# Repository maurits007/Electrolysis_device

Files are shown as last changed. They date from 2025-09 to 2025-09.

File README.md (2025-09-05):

# Electrolysis Device Controller – Arduino R4 Wifi

## Version
**v1.0** – Last updated: 2025-09-05  

---

## Table of Contents
1. [Overview](#overview)  
2. [Startup](#startup)  
3. [Normal Usage](#normal-usage)  
4. [Buttons](#buttons)  
5. [Main menu](#main-menu)  
6. [Advanced Settings / Calibration](#advanced-settings--calibration)  
7. [LED Indicators](#led-indicators)  
8. [Bugs / Troubleshooting](#bugs--troubleshooting) 
9. [Values achieved](#values-achieved) 

---

## Overview
This Arduino project allows you to control an electrolysis device via a physical interface (buttons and OLED) or a web interface through WiFi.  
You can set the desired current, the operating time, and monitor voltage, current, and resistance in real-time.

---

## Startup
1. The Arduino will create a WiFi hotspot:  
   - **SSID:** `ArduinoAP`  
   - **Password:** `12345678`  
2. Connect to the WiFi (if wanted) and access the web server using a browser:  
   - Type the IP address shown on the bottom of the OLED screen (usually `192.168.4.1`).  
3. Connect the electrolysis device to the PCB:  
   - **Red wire:** `Ld +`  
   - **Black wire:** `Ld -`  
   - If connected correctly, the LED should light **yellow/green** (not red).  

---

## Normal Usage
1. Start the device and optionally connect via WiFi.  
2. Connect the electrolysis device as described above.  
3. Select the desired current (`I want`) and time (`Time`).  
4. Press the **small button** to start:  
   - The LED turns **green** if running.  
   - The OLED shows `I real` (actual current) and elapsed time.  
5. When the reaction is complete:  
   - LED turns **blue**.  
   - The ending screen is displayed.  
   - Press the small button or use the web interface to restart.  

---

## Buttons

| Button | Function |
|---|---|
| **Encoder (turnable)** | Select a menu line by turning. Press to start editing the value. Press again to stop editing. |
| **Small button** | Start/stop electrolysis. LED indicates the device state. |

---

## Main menu
The OLED screen has **8 lines**:

| Line | Description |
|---|---|
| Time | Time passed / total wanted time |
| I want | Desired current |
| I real | Actual current through the device |
| V load | Voltage across the device (mV) |
| R load | Device resistance (ohms) – inaccurate if device is off |
| Reset time | Reset the timer to restart the electrolysis reaction |
| Advanced Settings | Access [calibration options](#advanced-settings--calibration ) and PCB selection |
| IP | IP address to access the web interface |

> Bottom-right corner: ❚❚ (paused) or ▶ (running)

---

## Advanced Settings / Calibration
The advanced menu has **5 lines**:

Here the PCB can be calibrated.

| Line | Description |
|---|---|
| PCB number | Select which PCB configuration to use (2 saved configurations supported) |
| Cur. res. | Current sense resistor value for calibration |
| A0 | Multiplier for output voltage calibration (`I load`) |
| A1 | Multiplier for measured current calibration (`I meas`) |
| Load | Multiplier for measured voltage over the load |

---

## LED Indicators

| Color | Meaning |
|---|---|
| Red | Device not connected correctly |
| Yellow | Electrolysis off |
| Green | Electrolysis running |
| Blue | Electrolysis finished |

---

## Bugs / Troubleshooting
- **OLED screen freezes:** Unplug and plug the Arduino back in.  
- **Red LED stays on:** Check that `Ld +` and `Ld -` are connected correctly.  
- **Keeps pausing:** There is a safety measure if there is too much power over the MOSFET. Increasing or decreasing the current both help decreasing the power and the device will be able to start again.

## Values achieved
- **No external voltage:** 210 mA
- **6V ext:** 350mA

---
-------
## Future extensions
- **Using external voltage:** First voltage dividers and zener diodes have to be added to the pins reading the voltage over the load to protect it against overvoltage.
- **using 3V3 as ADC reference:** Currently no significant improvements were found using it.

- **Improvements PCB:**
   1. Make holes LCD screen bigger.
   2. Correct orientation MOSFET or replace by through-hole MOSFET
   3. To use pin A4, A5 the screen has to be connected to QWIIC.

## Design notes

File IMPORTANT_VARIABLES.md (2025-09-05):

## deviceStats[7]
|Index | |
|-|-|
|0 |Last reset time|
|1 |Total wanted time (s)|
|2 |Desired current (mA)|
|3 |Actual current (mA)|
|4 |Load voltage (mV)|
|5 |Output enabled flag|
|6 |Resistance of the load (ohm)|

## correctionVariables[4][2]:
Here the calibration variables are saved.

||**Device 1** / **Device 2** | 
|----|---|
|1| A0 correction| 
|2| A1 correction|
|3| current_sense_resistor|
|4| load voltage correction|

## PIN Definition
| **Pin Nr.** | Meaning|
|---|-|
|A0 | Output Voltage (DAC)|
|A1 | Current Sense Resistor (ADC)|
|A2 | Load Voltage Negative (ADC)|
|A3 | Load Voltage Positive (ADC)|
|A4 | SDA (I2C)|
|A5 | SCL (I2C)|
|2  | Encoder A|
|3  | Encoder B|
|6  | Encoder Button|
|8  | Small Button|

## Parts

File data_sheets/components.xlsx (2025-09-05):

Reference | Qty | Value | RS-link | Found | Footprint | Datasheet
A1 | 1 | Arduino_Uno_R4_WiFi_Shield | //// | TRUE | PCM_arduino-library:Arduino_Uno_R4_WiFi_Shield | https://docs.arduino.cc/hardware/uno-r4-wifi
C1 | 1 | 100n | 199-2385 | TRUE | Capacitor_SMD:C_1210_3225Metric_Pad1.33x2.70mm_HandSolder | ~
D1 | 1 | LED_GBAR | already have them | TRUE | LED_THT:LED_D5.0mm-4_RGB | ~
D2,D3 | 2 | D_Zener | 738-5046 | TRUE | Diode_SMD:D_SOD-123 | ~
IC1 | 1 | AD8531ARZ-REEL | already have them | TRUE | Package_SO:SOIC-8_3.9x4.9mm_P1.27mm | https://www.analog.com/AD8531/datasheet
J2 | 1 | Conn_01x04_Socket | 3287528 (Farnell) | FALSE | Connector:NS-Tech_Grove_1x04_P2mm_Vertical | kicad-embed://Connector_i2c.pdf
J3 | 1 | Conn_01x04_Socket | magazijn | TRUE | Connector_Phoenix_MSTB:PhoenixContact_MSTBVA_2,5_4-G-5,08_1x04_P5.08mm_Vertical | ~
J4 | 1 | Conn_01x03_Pin | 702-0105, 233-9724 | TRUE | Connector_PinHeader_1.27mm:PinHeader_1x03_P1.27mm_Vertical | ~
Q1 | 1 | BS170 | 708-2393 | TRUE | Package_TO_SOT_SMD:SOT-23_Handsoldering | https://www.onsemi.com/pub/Collateral/BS170-D.PDF
R1 | 1 | 150 | 198-8555 | TRUE | Resistor_SMD:R_2512_6332Metric_Pad1.40x3.35mm_HandSolder | ~
R2,R3 | 2 | 90 | will use 100 | TRUE | Resistor_SMD:R_2512_6332Metric_Pad1.40x3.35mm_HandSolder | ~
R4 | 1 | 1k | 198-8564 | TRUE | Resistor_SMD:R_2512_6332Metric_Pad1.40x3.35mm_HandSolder | ~
R5 | 1 | 100 | 198-8549 | TRUE | Resistor_SMD:R_2512_6332Metric_Pad1.40x3.35mm_HandSolder | ~
R6 | 1 | 1R1 | 198-8566 | TRUE | Resistor_SMD:R_2512_6332Metric_Pad1.40x3.35mm_HandSolder | ~
R7 | 1 | 43k |  | TRUE | Resistor_SMD:R_2512_6332Metric_Pad1.40x3.35mm_HandSolder | ~
R9,R10 | 2 | 0 | 198-8545 | TRUE | Resistor_SMD:R_2512_6332Metric_Pad1.40x3.35mm_HandSolder | ~
R11,R12,R13,R14 | 4 | ~ |  | FALSE | Resistor_SMD:R_2512_6332Metric_Pad1.40x3.35mm_HandSolder | ~
U2 | 1 | MDOB | already have them | TRUE | Custom_footprints:MDOB128064V2V-WI | kicad-embed://display_oled.pdf
U3 | 1 | ~ | already have them | TRUE | Custom_footprints:MC32831
U4 | 1 | ~ | already have them | TRUE | Custom_footprints:PEC11R-4215K-S0012
R8 |  | 12k | 755-1344P | TRUE
 |  |  |  | FALSE
 |  |  |  | FALSE

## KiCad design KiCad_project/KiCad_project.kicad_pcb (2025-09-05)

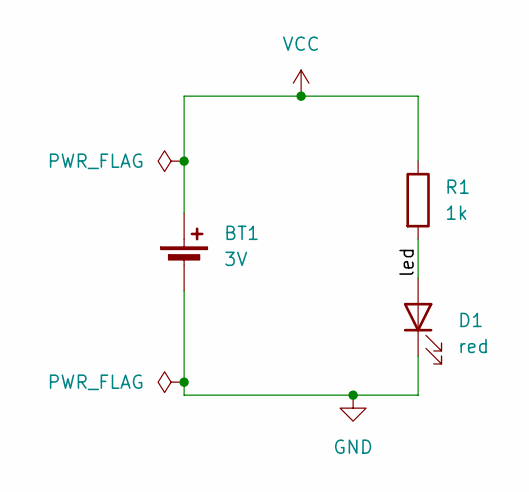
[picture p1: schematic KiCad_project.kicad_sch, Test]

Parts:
BT1: 3V; BatteryHolder_Keystone_1058_1x2032
D1: red; LED_D5.0mm
R1: 1k; R_Axial_DIN0309_L9.0mm_D3.2mm_P12.70mm_Horizontal

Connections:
/led: D1.2 (A), R1.2
GND: BT1.2 (-), D1.1 (K)
VCC: BT1.1 (+), R1.1

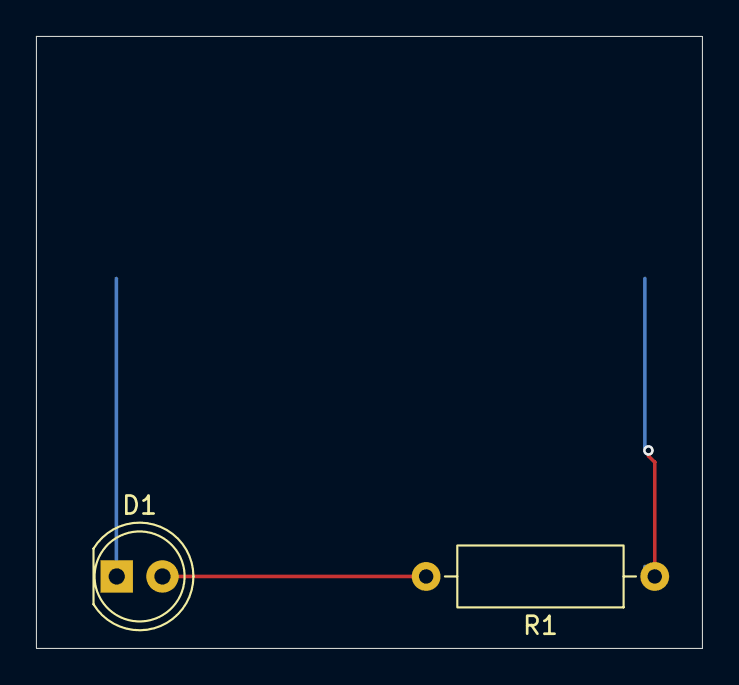
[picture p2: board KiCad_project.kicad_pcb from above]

Board: 2 copper layers, 37.0 x 34.0 mm, 3 parts (1 on the bottom side), 3 nets.

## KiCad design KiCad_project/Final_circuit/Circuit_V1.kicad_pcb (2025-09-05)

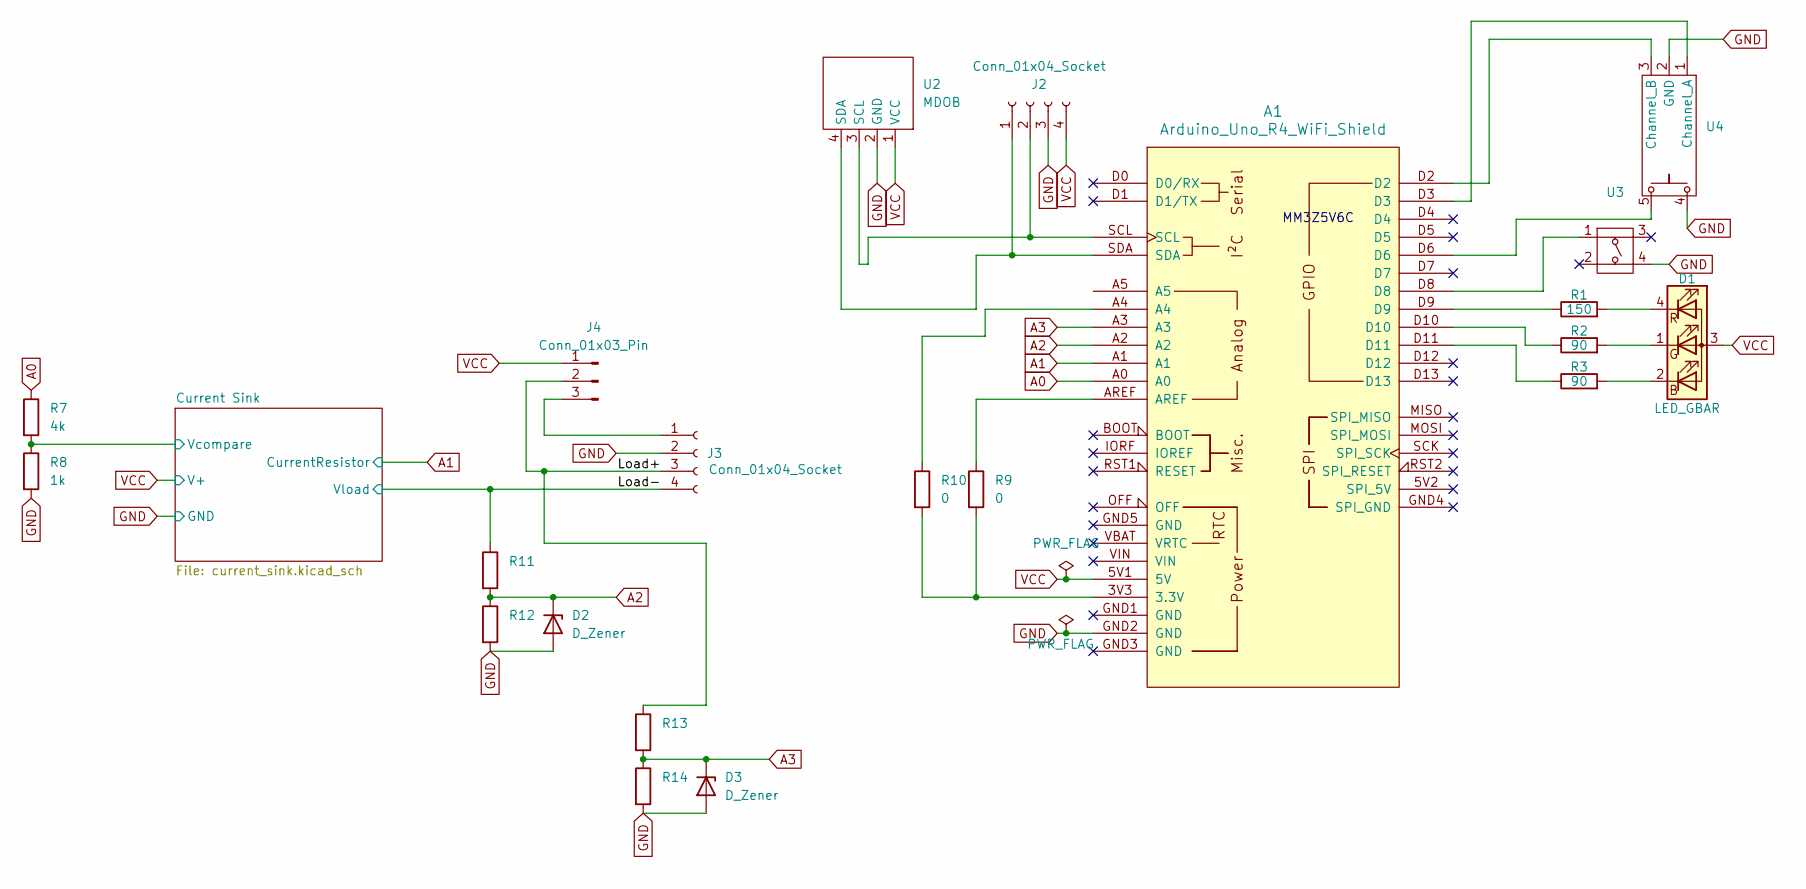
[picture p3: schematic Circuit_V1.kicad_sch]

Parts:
A1: Arduino_Uno_R4_WiFi_Shield
D1: LED_GBAR; LED_D5.0mm-4_RGB
D2, D3: D_Zener; D_SOD-123
J2: Conn_01x04_Socket; NS-Tech_Grove_1x04_P2mm_Vertical
J3: Conn_01x04_Socket; PhoenixContact_MSTBVA_2,5_4-G-5,08_1x04_P5.08mm_Vertical
J4: Conn_01x03_Pin; PinHeader_1x03_P1.27mm_Vertical
R1: 150; R_2512_6332Metric_Pad1.40x3.35mm_HandSolder
R2, R3: 90; R_2512_6332Metric_Pad1.40x3.35mm_HandSolder
R7: 4k; R_2512_6332Metric_Pad1.40x3.35mm_HandSolder
R8: 1k; R_2512_6332Metric_Pad1.40x3.35mm_HandSolder
R9, R10: 0; R_2512_6332Metric_Pad1.40x3.35mm_HandSolder
R11, R12, R13, R14: R_2512_6332Metric_Pad1.40x3.35mm_HandSolder
U2: MDOB; MDOB128064V2V-WI
U3: MC32831
U4: PEC11R-4215K-S0012

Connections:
/Current Sink/Vcompare: R7.2, R8.1; also elsewhere on the board
/Load+: J3.3, J4.2, R13.1
/Load-: J3.4, R11.1; also elsewhere on the board
A0: A1.A0, R7.1
A1: A1.A1; also elsewhere on the board
A2: A1.A2, D2.1 (K), R11.2, R12.1
A3: A1.A3, D3.1 (K), R13.2, R14.1
GND: A1.GND2 (GND), D2.2 (A), D3.2 (A), J2.3, J3.2, R8.2, R12.2, R14.2, U2.2 (GND), U3.4, U4.2 (GND), U4.4; also elsewhere on the board
unnamed: A1.3V3 (3.3V), R9.2, R10.2
unnamed: A1.A4, R10.1
unnamed: A1.AREF, R9.1
unnamed: A1.D6, U4.5
unnamed: A1.D8, U3.1
unnamed: A1.D9, R1.1
unnamed: A1.D10, R2.1
unnamed: A1.D11, R3.1
unnamed: D1.2 (BK), R3.2
unnamed: D1.1 (GK), R2.2
unnamed: D1.4 (RK), R1.2
unnamed: A1.SDA, J2.1, U2.4 (SDA)
unnamed: A1.SCL, J2.2, U2.3 (SCL)
unnamed: J3.1, J4.3
unnamed: A1.D3, U4.1 (Channel_A)
unnamed: A1.D2, U4.3 (Channel_B)
VCC: A1.5V1 (5V), D1.3 (A), J2.4, J4.1, U2.1 (VCC); also elsewhere on the board

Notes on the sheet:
MM3Z5V6C

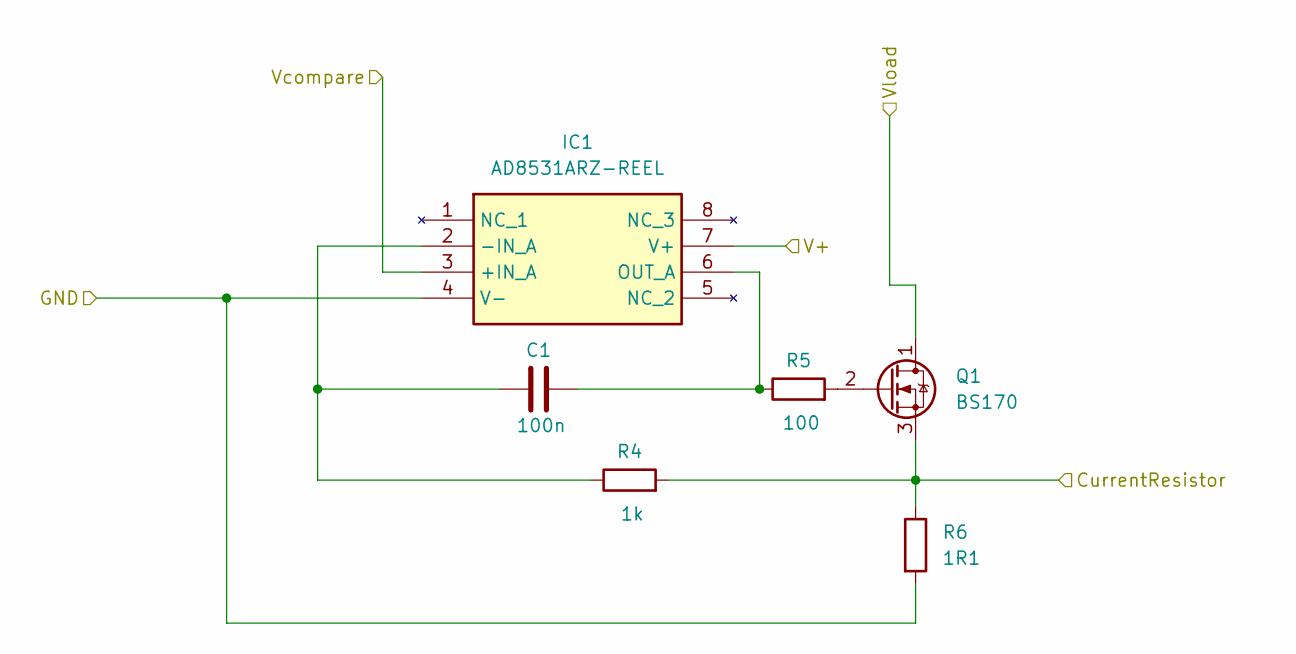
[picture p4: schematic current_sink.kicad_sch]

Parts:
C1: 100n; C_1210_3225Metric_Pad1.33x2.70mm_HandSolder
IC1: AD8531ARZ-REEL; SOIC-8_3.9x4.9mm_P1.27mm; Mouser Part Number 584-AD8531ARZ-R
Q1: BS170; SOT-23_Handsoldering
R4: 1k; R_2512_6332Metric_Pad1.40x3.35mm_HandSolder
R5: 100; R_2512_6332Metric_Pad1.40x3.35mm_HandSolder
R6: 1R1; R_2512_6332Metric_Pad1.40x3.35mm_HandSolder

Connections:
/Current Sink/Vcompare: IC1.3 (+IN_A); also elsewhere on the board
/Load-: Q1.1 (D); also elsewhere on the board
A1: Q1.3 (S), R4.2, R6.1; also elsewhere on the board
GND: IC1.4 (V-), R6.2; also elsewhere on the board
unnamed: C1.1, IC1.2 (-IN_A), R4.1
unnamed: C1.2, IC1.6 (OUT_A), R5.1
unnamed: Q1.2 (G), R5.2
VCC: IC1.7 (V+); also elsewhere on the board

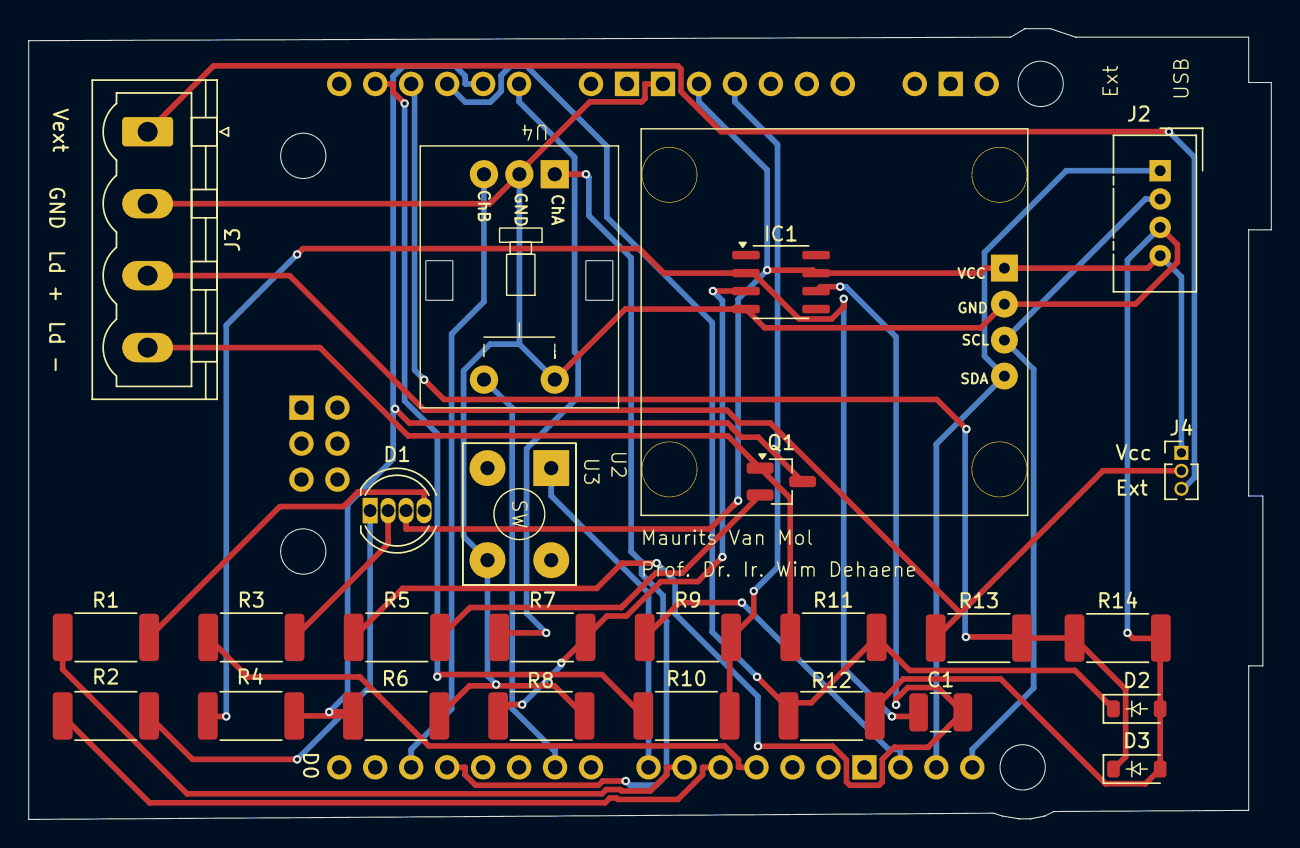
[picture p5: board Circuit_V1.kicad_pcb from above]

Board: 2 copper layers, 87.8 x 55.8 mm, 27 parts (0 on the bottom side), 28 nets.

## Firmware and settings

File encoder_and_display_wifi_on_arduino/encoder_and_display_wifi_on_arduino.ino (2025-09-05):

//===================== CALIBRATION =======================
#define CURRENT_SENSE_RESISTOR_1 0.56
#define CURRENT_SENSE_RESISTOR_2 1
float current_sense_resistor[2] =  {CURRENT_SENSE_RESISTOR_1, CURRENT_SENSE_RESISTOR_2};
float A0Correction[2] = {1.02, 1.07};
float A1Correction[2] = {1, 0.91};
float loadVoltageCorrection[2] = {1, 1};
float correctionVariables[4][2] = {
  { A0Correction[0], A0Correction[1] },        // A0
  { A1Correction[0], A1Correction[1] },        // A1
  { current_sense_resistor[0], current_sense_resistor[1] }, // current sense
  { loadVoltageCorrection[0], loadVoltageCorrection[1] }    // load voltage
};
float oldCorrectionVariables[4][2];
int numbPCB = 0;
#define Vdd 4.56
#define Vext 4.56


//====================== WIFI SETTINGS =======================
#include <WiFiS3.h>
#include "webpage.h"
    
WiFiServer server(80);  // Create a WebServer object on port 80
char ssid[] = "ArduinoAP";       // Network SSID
char pass[] = "12345678";        // Password (at least 8 chars)


//====================== LIBRARIES =======================

#include <EEPROM.h>
#include <Wire.h>
#include <Adafruit_GFX.h>
#include <Adafruit_SSD1306.h>
#include "utils.h"

//=============Function prototypes===================
void redOn();
void greenOn();
void yellowOn();
void blueOn();
void pinkOn();
void readEncoder();
void onEncoderButtonPress();
void onSmallButtonPress();


//======================Global Variables======================
int timeFinished = 0; //Time when it finished, to display in ending screen
bool overVoltage = false; //if goes high, it shows overvoltage warning in stats screen

//====================== PIN DEFINITIONS =======================
#define SDA_PIN A4   // adjust if not on Arduino Uno/Nano
#define SCL_PIN A5
#define ENCODER_PIN_A       3
#define ENCODER_PIN_B       2
#define ENCODER_BUTTON_PIN  6
#define SMALL_BUTTON_PIN    8
#define OLED_RESET         4
#define ledR 9
#define ledB 11
#define ledG 10
/*****************
 Pin Connections:
   A0 -> Output Voltage
   A1 -> Current Sense Resistor
   A2 -> Load Voltage Negative
   A3 -> Load Voltage Positive
   A4 -> SDA (I2C)
   A5 -> SCL (I2C)
   2  -> Encoder A
   3  -> Encoder B
   6  -> Encoder Button
   8  -> Small Button
******************/


//====================== OLED Display =======================
#define SCREEN_WIDTH  128
#define SCREEN_HEIGHT 64
Adafruit_SSD1306 display(SCREEN_WIDTH, SCREEN_HEIGHT, &Wire, OLED_RESET);



/******************** Encoder Variables *******************/
volatile int encoderCount = 0; 
volatile bool encoderButtonPressedFlag = false;
volatile bool smallButtonPressedFlag = false;

volatile unsigned long lastEncoderButtonInterrupt = 0; 
volatile unsigned long lastSmallButtonInterrupt = 0;

unsigned long lastIncrementTime = micros();
unsigned long lastDecrementTime = micros();

const int encoderFastStep = 3; //if quickly turning, it will change by this value
const int encoderDebounceMicros = 25000; //reduce against bouncing


/******************** Menu System *************************/
bool isEditing = false;
int menuCursor = 0;
bool showStatsScreen = 1;
bool showAdvancedMenu = 0;
bool reset = 1; //reset the values of stats screen
bool reset_ending = 0; //lets the ending screen know it should reset
bool toggleStartWifi = 0; //if start is pressed by web server
int elapsedTime = 0;
int timePassed = 0;



/******************** Measurements ************************/
int deviceStats[7] = {0, 60, 3, 44, 0, false, 0}; 
// [0] Last reset time
// [1] Total wanted time (s)
// [2] Desired current (mA)
// [3] Actual current (mA)
// [4] Load voltage (mV)
// [5] Output enabled flag
// [6] Resistance of the load (ohm)

int oldWantedTime = deviceStats[1]; //to check if it changed to updated EEPROM
int oldDesiredCurrent = deviceStats[2]; //idem
int oldnumbPCB = numbPCB; //idem
int voltageSenseRaw = 0; //raw value from ADC over current sense resistor
float voltageSense = 0.0;  //voltage over current sense resistor
int outputVoltageCommand = 0; //digital value to set output voltage over DAC


/******************** Setup *******************************/
void setup() {
  // ====== Serial Setup ======
  Serial.begin(500000);
  pinMode(ledR, OUTPUT);
  pinMode(ledB, OUTPUT);
  pinMode(ledG, OUTPUT);
  blueOn();
  while(!Serial);  // wait for Serial

  // ====== Encoder Setup ======
  // analogReference(AR_EXTERNAL);
  pinMode(ENCODER_PIN_A, INPUT_PULLUP);
  pinMode(ENCODER_PIN_B, INPUT_PULLUP);
  pinMode(ENCODER_BUTTON_PIN, INPUT_PULLUP);
  pinMode(SMALL_BUTTON_PIN, INPUT_PULLUP);
  attachInterrupt(digitalPinToInterrupt(ENCODER_PIN_A), readEncoder, CHANGE);
  attachInterrupt(digitalPinToInterrupt(ENCODER_PIN_B), readEncoder, CHANGE);
  attachInterrupt(digitalPinToInterrupt(ENCODER_BUTTON_PIN), onEncoderButtonPress, FALLING);
  attachInterrupt(digitalPinToInterrupt(SMALL_BUTTON_PIN), onSmallButtonPress, FALLING);

  // ====== Analog Setup ======
  analogReadResolution(12);
  analogWriteResolution(12);

  // ====== EEPROM Setup ======
  EEPROM.get(0, deviceStats[1]);
  EEPROM.get(4, deviceStats[2]);
  EEPROM.get(8, numbPCB);
  EEPROM.get(16, correctionVariables);


  oldDesiredCurrent = deviceStats[2]; //save values from EEPROM
  oldWantedTime = deviceStats[1];
  oldnumbPCB = numbPCB;
  for (int i=0; i<4; i++){
    for (int j=0; j<2; j++){
      oldCorrectionVariables[i][j] = correctionVariables[i][j];
    }
  }


  // ====== OLED Setup ======
  if (!display.begin(SSD1306_SWITCHCAPVCC, 0x3C)) {
    Serial.println(F("SSD1306 allocation failed"));
    while (true);
  }
  display.clearDisplay();
  display.fillScreen(SSD1306_BLACK);
  display.setTextColor(SSD1306_WHITE);
  display.setTextSize(2);
  display.setCursor(0, 0);
  display.println("Connecting");
  display.println("to the");
  display.println("wifi!");
  display.setTextSize(1);
  display.println("Small button -> no wifi");
  display.display();

  // ====== WiFi Setup ======
  Serial.println("Starting Access Point…");
  int status = WiFi.beginAP(ssid, pass);
  if (status != WL_AP_LISTENING) {
    Serial.println("Failed to start AP");
    while (true);
  }
  // Print the IP address of the AP (usually 192.168.4.1)
  Serial.print("AP started. IP address: ");
  Serial.println(WiFi.localIP());
  server.begin();

}


/******************** Main Loop ***************************/
void loop() {
  //===================== Read Sensors =======================
    int voltageLoadRawPos = analogRead(A3);//voltage over the load
    int voltageLoadRawNeg = analogRead(A2);
    int voltageLoadDiffRaw = voltageLoadRawPos - voltageLoadRawNeg;
    deviceStats[4] = correctionVariables[3][numbPCB]*Vext*1000.0 * voltageLoadDiffRaw / 4096;
    voltageSenseRaw = analogRead(A1); //current sense resistor
    voltageSense = correctionVariables[1][numbPCB]*Vext*1000.0 * voltageSenseRaw / (4096.0);
    deviceStats[3] = voltageSense / correctionVariables[2][numbPCB];
    // deviceStats[3] = voltageSense;
    deviceStats[6] = deviceStats[4]/deviceStats[3]; //resistance of the load
    int vdsRaw = voltageLoadRawNeg - voltageSenseRaw; //voltage over the mosfet
    float vds = correctionVariables[0][numbPCB]*Vext * vdsRaw / 4096.0;
    float powerDissipated = vds * deviceStats[3]; //in mW
    if(powerDissipated > 400){ //if too much power dissipated, turn off output
      overVoltage = true;
    }
    // Calculate output voltage command
    outputVoltageCommand = correctionVariables[0][numbPCB]*deviceStats[2] * correctionVariables[2][numbPCB] * 4096 / (Vdd*1000);
    // Write to output
    if (!deviceStats[5]) {
      analogWrite(A0, 0);
    } else {
      analogWrite(A0, outputVoltageCommand);
    }
    //===================== LIGHTS =======================

    if(!showStatsScreen){
      blueOn();
    }
    else if(deviceStats[5]){
        greenOn();
      }
    else if(voltageLoadDiffRaw > 4096*0.93){
      redOn();
    }
    else{
      yellowOn();
    }
  //===================== MENU =======================
  const char* (*menuFunctions[])(int*, bool*, bool*, int*, bool) = { //functions for each menu item
    timeMenuItem,
    desiredCurrentMenuItem,
    resetTimeMenuItem,
    advancedScreenItem,
    actualCurrentMenuItem,
    voltageMenuItem,
    resistanceMenuItem,
    ipMenuItem
  };  
  AdvancedItemFn menuFunctionsAdvanced[] = {
    PCB_numberMenuItem,
    currentResistorMenuItem,
    A0CorrectionMenuItem,
    A1CorrectionMenuItem,
    loadCorrectionMenuItem
    // add the others here
  };

  int menuOrder[] = {0, 1, 4, 5, 6, 2, 3, 7};
  int menuOrderAdvanced[] = {0, 1, 2, 3, 4};
  //check if time is finished
  if(((millis()-deviceStats[0])/1000 >= deviceStats[1]) && deviceStats[5]){
    showStatsScreen = 0;
    timeFinished = (millis() - deviceStats[0])/1000;
  }
  if(showAdvancedMenu){
    renderAdvancedMenu(
        menuFunctionsAdvanced,
        correctionVariables,
        sizeof(menuFunctionsAdvanced) / sizeof(menuFunctionsAdvanced[0]),
        (bool*)&encoderButtonPressedFlag,
        &menuCursor,
        &isEditing,
        (int*)&encoderCount,
        menuOrderAdvanced,
        (bool*)&smallButtonPressedFlag,
        &reset
      );
  }
  else if(showStatsScreen){
    showStatsScreen = renderStatsMenu(
        menuFunctions,
        deviceStats,
        sizeof(menuFunctions) / sizeof(menuFunctions[0]),
        (bool*)&encoderButtonPressedFlag,
        &menuCursor,
        &isEditing,
        (int*)&encoderCount,
        menuOrder,
        (bool*)&smallButtonPressedFlag, 
        &reset,
        &toggleStartWifi
      );
  }
  else{
    showStatsScreen = renderEnding(deviceStats, (bool*)&smallButtonPressedFlag, &reset_ending);
    deviceStats[5] = 0;
    reset = 1;
  }


  //===================== SAVE EEPROM =======================
  if(oldDesiredCurrent != deviceStats[2]){
    EEPROM.put(4, deviceStats[2]);
    oldDesiredCurrent = deviceStats[2];
  }
  if(oldWantedTime != deviceStats[1]){
    EEPROM.put(0, deviceStats[1]);
    oldDesiredCurrent = deviceStats[1];
  }  
  if(oldnumbPCB != numbPCB){
    EEPROM.put(8, numbPCB);
    oldnumbPCB = numbPCB;
  }

  if(!arraysEqual2D(oldCorrectionVariables, correctionVariables, 4, 2)){
    EEPROM.put(16, correctionVariables);
      for (int i=0; i<4; i++){
        for (int j=0; j<2; j++){
          oldCorrectionVariables[i][j] = correctionVariables[i][j];
        }
      }
  }
  //===================== TIME PASSED FOR DISPLAYING WIFI =======================
  if (!showStatsScreen){ //
    timePassed = deviceStats[1];
  }
  else if(!deviceStats[5]){
    timePassed = elapsedTime/1000;
  }
  else{
    timePassed = (millis() - deviceStats[0])/1000;
  }

//=====================WIFI======================
  WiFiClient client = server.available();   // check for incoming client
  if (client) {
    Serial.println("New client connected");
    String currentLine = "";
    String request = "";
    unsigned long startTime = millis(); // Add a timeout to prevent an infinite loop

  // Read the request line by line, up to the end of the headers
  while (client.connected() && (millis() - startTime < 50)) {
    if (client.available()) {
      //read request
      char c = client.read();
      request += c;
      if (c != '\r') {
        currentLine += c;
      }
      if (c == '\n') {
        // We've received a complete line
        if (currentLine.length() == 0) {
          // This marks the end of the headers, so we can stop
          break;
        }

        // Handle GET requests first, as they are a single line
        if (currentLine.startsWith("GET /updateCurrent")) {
          int value = currentLine.substring(currentLine.indexOf("value=") + 6).toInt();
          if (value > 0) {
            deviceStats[2] = value;
          }
          client.println("HTTP/1.1 200 OK");
          client.println();
          client.stop(); // Stop the client after a successful response
          return;
        }

        if (currentLine.startsWith("GET /updateTime")) {
          int value = currentLine.substring(currentLine.indexOf("value=") + 6).toInt();
          if (value > 0) {
            deviceStats[1] = value;
          }
          client.println("HTTP/1.1 200 OK");
          client.println();
          client.stop();
          return;
        }

        if (currentLine.startsWith("GET /toggleRun")) {
          toggleStartWifi = 1;
          client.println("HTTP/1.1 200 OK");
          client.println();
          client.stop();
          return;
        }

        if (currentLine.startsWith("GET /restart")) {
          reset_ending = 1;
          reset = 1;
          client.println("HTTP/1.1 200 OK");
          client.println();
          client.stop();
          return;
        }

        if (currentLine.startsWith("GET /stats")) { // Return stats as JSON to send to webpage to update
          String json = "{";
          json += "\"desiredCurrent\":" + String(deviceStats[2]) + ",";
          json += "\"measuredCurrent\":" + String(deviceStats[3]) + ",";
          json += "\"loadVoltage\":" + String(deviceStats[4]) + ",";
          json += "\"time\":\"" + String(timePassed) + "/" + String(deviceStats[1]) + "\",";
          json += "\"deviceOn\":" + String(deviceStats[5]) + ",";
          json += "\"showStatsScreen\":" + String(showStatsScreen) + ",";
          json += "\"loadResistance\":" + String(deviceStats[6]);
          json += "}";
          
          client.println("HTTP/1.1 200 OK");
          client.println("Content-Type: application/json");
          client.println("Connection: close");
          client.println();
          client.println(json);
          client.stop();
          return;
        }
        
        currentLine = ""; // Reset the line for the next one
      }
    }
  }

  Serial.println("Headers: " + request);

  // If we reach here, no GET request was handled, so check for POST data
  int contentLength = 0;
  int idxLen = request.indexOf("Content-Length: ");
  if (idxLen >= 0) {
    int idxEnd = request.indexOf("\r\n", idxLen);
    contentLength = request.substring(idxLen + 16, idxEnd).toInt();
  }

  // --- Read body (POST data) ---
  String body = "";
  while (client.connected() && body.length() < contentLength) {
    if (client.available()) {
      body += (char)client.read();
    }
  }

  Serial.println("Body: " + body);

  bool handledPost = false;

  // ---- Parse POST form data ----
  if (body.indexOf("current=") >= 0) {
    int idx = body.indexOf("current=") + 8;
    int val = body.substring(idx).toInt();
    if (val > 0) {
      deviceStats[2] = val;
    }
    Serial.print("Updated current: ");
    Serial.println(deviceStats[2]);
    handledPost = true;
  }

  if (body.indexOf("time=") >= 0) {
    int idx = body.indexOf("time=") + 5;
    int val = body.substring(idx).toInt();
    if (val > 0) {
      deviceStats[1] = val;
    }
    Serial.print("Updated time: ");
    Serial.println(deviceStats[1]);
    handledPost = true;
  }

  if (body.indexOf("run=0") >= 0) {
    toggleStartWifi = 1;
    Serial.println("Device turned on/off");
    handledPost = true;
  }

  if (body.indexOf("run=1") >= 0) {
    reset_ending = 1;
    reset = 1;
    Serial.println("Device reset");
    handledPost = true;
  }

  // ---- Send response ----
  if (handledPost) {
    client.println("HTTP/1.1 303 See Other");
    client.println("Location: /");
    client.println("Connection: close");
    client.println();
  } else {
    // Normal GET → return the page
    client.println("HTTP/1.1 200 OK");
    client.println("Content-type:text/html");
    client.println("Connection: close");
    client.println();
    sendHTML(client); // generate with updated state
  }

  client.stop();
  Serial.println("Client disconnected");
  }

}



//==================UTILS=======================

bool arraysEqual2D(float arr1[][2], float arr2[][2], int rows, int cols) {
  for (int i = 0; i < rows; i++) {
    for (int j = 0; j < cols; j++) {
      if (arr1[i][j] != arr2[i][j]) {
        return false;
      }
    }
  }
  return true;
}
/******************** Encoder ISR *************************/
void readEncoder() {
  static uint8_t previousState = 3;
  static int8_t encoderDelta = 0;

  const int8_t encoderStateTable[] = {
     0, -1,  1, 0,
     1,  0,  0, -1,
    -1,  0,  0, 1,
     0,  1, -1, 0
  };

  previousState <<= 2;
  if (digitalRead(ENCODER_PIN_A)) previousState |= 0x02;
  if (digitalRead(ENCODER_PIN_B)) previousState |= 0x01;
  encoderDelta += encoderStateTable[previousState & 0x0F];

  if (encoderDelta > 1) {
    encoderCount += (micros() - lastIncrementTime < encoderDebounceMicros) ? encoderFastStep : 1;
    lastIncrementTime = micros();
    encoderDelta = 0;
  } else if (encoderDelta < -1) {
    encoderCount -= (micros() - lastDecrementTime < encoderDebounceMicros) ? encoderFastStep : 1;
    lastDecrementTime = micros();
    encoderDelta = 0;
  }

}

/******************** Button ISRs *************************/
void onEncoderButtonPress() {
  unsigned long now = micros();
  if (now - lastEncoderButtonInterrupt > 200000) {
    encoderButtonPressedFlag = true;
    lastEncoderButtonInterrupt = now;
  }
}

void onSmallButtonPress() {
  unsigned long now = micros();
  if (now - lastSmallButtonInterrupt > 500000) {
    smallButtonPressedFlag = true;
    lastSmallButtonInterrupt = now;
  }
}



/******************** LED Control *************************/

void redOn(){
  analogWrite(ledR, 3000);  
  analogWrite(ledG, 4095);
  analogWrite(ledB, 4095);
}
void greenOn(){
  analogWrite(ledR, 4095);  
  analogWrite(ledG, 3000);
  analogWrite(ledB, 4095);
}
void yellowOn(){
  analogWrite(ledR, 3000);  
  analogWrite(ledG, 3500);
  analogWrite(ledB, 4095);
}

void blueOn(){
  analogWrite(ledR, 4095);
  analogWrite(ledG, 4095);
  analogWrite(ledB, 3000);
}

void pinkOn(){
  analogWrite(ledR, 0);
  analogWrite(ledG, 3000);
  analogWrite(ledB, 2000);

}

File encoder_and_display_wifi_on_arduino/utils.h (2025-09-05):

#include <Adafruit_GFX.h>
#include <Adafruit_SSD1306.h>

// Display instance is declared elsewhere
extern Adafruit_SSD1306 display;

void resetTime(int deviceStats[]); //resets the time
void drawPlayButton();
void drawStopButton();
void drawWifiIcon(int x, int y);
int pauseTimestamp = 0; //holds the time when paused
extern int timeFinished; //holds the time when it finished
extern int elapsedTime; //holds the elapsed time when paused
extern bool showAdvancedMenu; //if goes high, it shows the advanced menu
extern bool overVoltage; //if goes high, it should pause
bool showEndingScreen = false; //if goes high, it shows the ending screen

typedef const char* (*AdvancedItemFn)(float correctionVariables[][2], //function pointer type for advanced menu items
                                      bool* isEditing,
                                      bool* encoderButtonPressed,
                                      int* encoderValue,
                                      bool isSelected);


// ======================= MENU RENDERING FUNCTIONS =======================

int renderStatsMenu( //displays the stats menu, returns if it should stay in stats menu or go to ending screen
    const char* (*menuFunctions[])(int*, bool*, bool*, int*, bool), //functions for each menu item 
    int deviceStats[], //array holding device stats ([0] Last reset time, [1] Total wanted time (s), [2] Desired current (mA), [3] Actual current (mA), [4] Load voltage (mV), [5] Output enabled flag, [6] Resistance of the load (ohm))
    int functionCount, //number of functions in menuFunctions
    bool *encoderButtonPressed,  //gets high when encoder button is pressed
    int *menuCursor, //current position of the cursor in the menu
    bool *isEditing, //it is high if the user is editing a value
    int *encoderValue, //value from the encoder, it will change if the user turns the encoder
    int *menuOrder, //gives the order in which menuFunctions should be displayed on the screen
    bool *smallButtonPressed, //gets high when small button is pressed
    bool *reset, //gets send when reseting from finished screen
    bool *toggleStartWifi //goes high if start is pressed by wifi
) {
    showEndingScreen = false; // reset ending screen flag
    bool encoderButtonHandled = false; // To prevent multiple toggles from a single press
    

    //handle reset
    if(*reset){ //it returns from finish screen so everything should get reset
        *reset = false; // Reset the flag after processing
        *menuCursor = 0; // Reset cursor position
        *encoderValue = 0; // Reset encoder value
        *isEditing = false; // Reset editing state
        deviceStats[5] = false; // Reset run/pause state
        deviceStats[0] = millis(); // Reset start time
        elapsedTime = 0; // Reset elapsed time
        *toggleStartWifi = false; // Reset toggle wifi state
    }

    if (overVoltage){
        deviceStats[5] = 0; // Toggle run/pause state
        *isEditing = false; // Exit editing mode if toggling pause/resume
        elapsedTime = millis() - deviceStats[0];
        overVoltage = false;   
    }
    // Handle small button toggle (pause/resume)
    if (*smallButtonPressed or *toggleStartWifi) {
        *toggleStartWifi = false; // Reset the flag after processing
        *smallButtonPressed = false;
        deviceStats[5] = !deviceStats[5]; // Toggle run/pause state
        *isEditing = false; // Exit editing mode if toggling pause/resume
        if (deviceStats[5]) { // Resuming, this will make the current time accurate
            deviceStats[0] = millis() - elapsedTime; // Resume from paused state
            elapsedTime = 0;
        } else { // Keep the time when paused
            elapsedTime = millis() - deviceStats[0];
        }
    }

    // Encoder button and cursor handling
    if (!deviceStats[5]) { // Only allow menu interaction when paused
        if (*encoderButtonPressed) { //if button pressed, reset flags and make encodervalue, menucursor
            *encoderButtonPressed = false; // Reset encoder button state after processing
            encoderButtonHandled = true; // Mark that the button press has been handled

            *isEditing = !(*isEditing); 
            if (!*isEditing) {
                *encoderValue = *menuCursor;
            }
        }

        if (!*isEditing) { //change menucursor depending on encodervalue, but make sure it is in bounds
            if (*encoderValue < 0) {
                *encoderValue = 0;
            } else if (*encoderValue > 3) {
                *encoderValue = 3;
            }
            *menuCursor = *encoderValue;
        }
    } else { //if running, menu shouldn't be changeable
        if(*encoderButtonPressed){
            *encoderButtonPressed = false; // Reset encoder button but shouldn't do anything
        }
        *menuCursor = -1; // Disable menu cursor when running
        *encoderValue = 0;
        *isEditing = false;
    }



    // Menu display
    display.clearDisplay();
    display.fillScreen(SSD1306_BLACK);
    display.setTextColor(SSD1306_WHITE);
    display.setTextSize(1);
    display.setCursor(0, 0);

    for (int i = 0; i < functionCount; i++) {
        int menuIndex = menuOrder[i];

        if (*menuCursor == menuIndex && *isEditing) { //if changing a value, it should be white
            display.setTextColor(SSD1306_BLACK, SSD1306_WHITE);
        } else {
            display.setTextColor(SSD1306_WHITE, SSD1306_BLACK);
        }

        display.write(menuIndex == *menuCursor ? '*' : ' '); //put a * if selected
        display.println(menuFunctions[menuIndex](deviceStats, isEditing, &encoderButtonHandled, encoderValue, *menuCursor == menuIndex)); //outputs what should be displayed
    }

    deviceStats[5] == false ? drawStopButton() : drawPlayButton(); //display play button
    drawWifiIcon(115, 10);   // adjust offsets if cut off
    display.display();

    return !showEndingScreen;

}
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

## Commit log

2025-09-05 Added the files needed for the arduino
2025-09-05 added data sheets
    [components.xlsx]
2025-09-05 moved components excel
    [components.xlsx]
2025-09-05 changed readme
    [components.xlsx]
